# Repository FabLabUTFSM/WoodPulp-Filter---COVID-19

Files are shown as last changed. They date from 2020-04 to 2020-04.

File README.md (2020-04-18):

# Wood Pulp Filter for Covid - 19

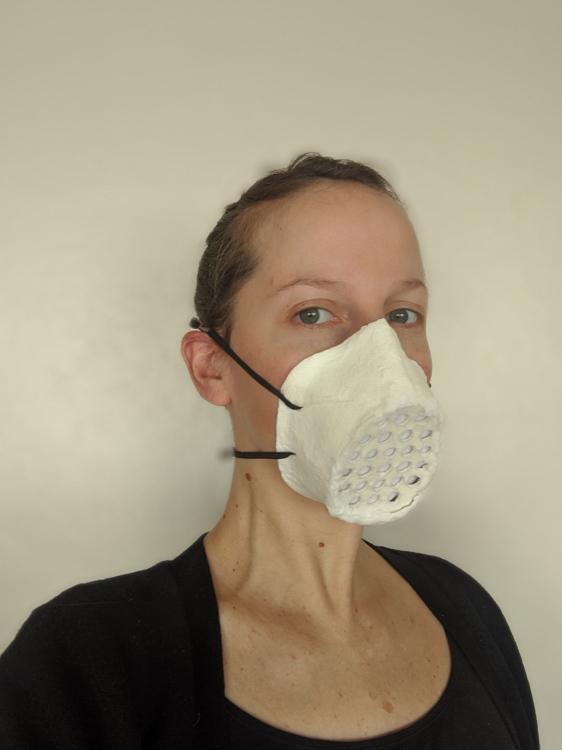
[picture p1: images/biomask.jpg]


This project is been developed by 
[Paloma Gonzalez](http://palomagr.mit.edu/index.html) and 
[José Tomás Domínguez](https://github.com/josetomas) in a collaboration of 
[Arauco ](https://www.arauco.cl)and [UTFSM Fablab](https://www.fablabs.io/labs/fablabutfsm).

COVID-19 has generated a global demand for face masks that our supply chains haven't been able to satisfy. Therefore, there is a huge need to create new materials and manufacturing methods to fabricate face masks and filters.  We are working on a wood pulp filter that protects from Covid - 19, and  could potentially be produced anywhere where there is a wood pulp factory. Wood pulp factories are present in most regions of the world.

Our goal is to physically modify wood pulp sheets to achieve the filtering performance of a N95 filter to produce a functional 
layer for respirators / masks / PPE for the corona viruses. 
[Wood pulp is the raw material for paper towels with the capacity of filtering particles of 0.3 μm.](https://smartairfilters.com/en/blog/paper-towel-effective-against-viruses-diy-mask/)
The corona virus measures approximately 0.1 μm. We can modify the compaction of the layers and/ or the size of the fibers to increase their filtering capacity / breathability. 

## Filter + Half Face Mask
**According to our calculations the half mask will cost $0,12 and the filter will cost $0,1.**  We will make updates to the cost whenever we have new info. We still aim for the cheapest possible option.

We are also developing a face mask which filters can be exchanged, 
completely out of molded wood pulp, taking advantage of our raw material.
[Our design is based on Wasp’s design](https://www.3dwasp.com/en/3d-printed-mask-from-3d-scanning/) but we are looking to work with molding 
and/or 2 mold processes instead of 3D printing. It is crucial to be able to mass produce the half masks. 

The advantage of Wasp design is that shape is ergonomic and the filters are held on the inside side of the mask, decreasing the contamination of the filters when changing them. 
There are also fabric masks in which these filters could work [like this one, the HKMask](https://diymask.site/). [We found carboard masks that also do the trick](http://bumask.ru/eng)

Molded wood pulp is meant to be a disposable material and it is 100% biodegradable as all the additives we are suing are. 
This is a characteristic that we want to take advantage of as after the pandemic we wouldn't want to have 
polluted the environment with more waste. This also means that the half masks will last less than N95 or other masks. We embrace such short temporality, and will 
asses it to notice our users. We expect that these protective equipment lasts 3 to 4 weeks.

## Filter Key Parameters to measure [[2](https://scientificfilters.com/wp-content/uploads/2016/03/BasicFiltrationConcepts.pdf)]
- Scanning Electron Microscope [SEM](https://en.wikipedia.org/wiki/Scanning_electron_microscope): This tests characterize the materials porosity. Target: < 0.1 um. 
        - **Update:** Camron did [SEM](SEM.md) imaging.
- Particle Retention Rate: "In a filtration process, the particle retention efficiency of a depth-type filter is expressed in terms of the particle size (in µm) at which a retention
level of 98% of the total number of particles initially challenging the filter is
obtained". Target: 95%
- Preassure Drop: The higher the pressure drop, the harder it is to breathe. Target: <5.82 [mmH20] at a flow rate of 32 [L/min]. 

We are following [FDA COVID-19 Face Mask Public Health Guidelines ](https://gitlab.cba.mit.edu/palomagr/wood-pulp-filter/-/blob/master/References/COVID19-Face-Masks-Guidance.pdf)

All this tests could be replaced by a DOP ([DOP Guideline](http://www.eacoontario.com/pdf/2013/Revised%20August%2027%202013%20DOP%20PAO%20HEPA%20IntegrityTesting%20Procedure.pdf)). 

## Filter Development
Wood pulp sheets have the following disadvantages:
- Hydrophilic, absorbs any liquid very fast so it could have a lower life expectancy and could absorb contaminated droplets, this can be controlled through design or modifying the material properties. 
- Due to air flow, the user could inhale wood pulp fibers, we are adding wood pulp based fabrics to act as a filter. It’s relevant to point out that wood fibers aren’t toxic, you just can’t digest them. 
- These filters will have a shorter life than plastic filters, we expect them to be replaced every 4 hours.  

### Raw Material for the filter and mask

Celulose comes in letter size sheets, 21.59 cm. X 27.94 cm with a thikness of 1mm.

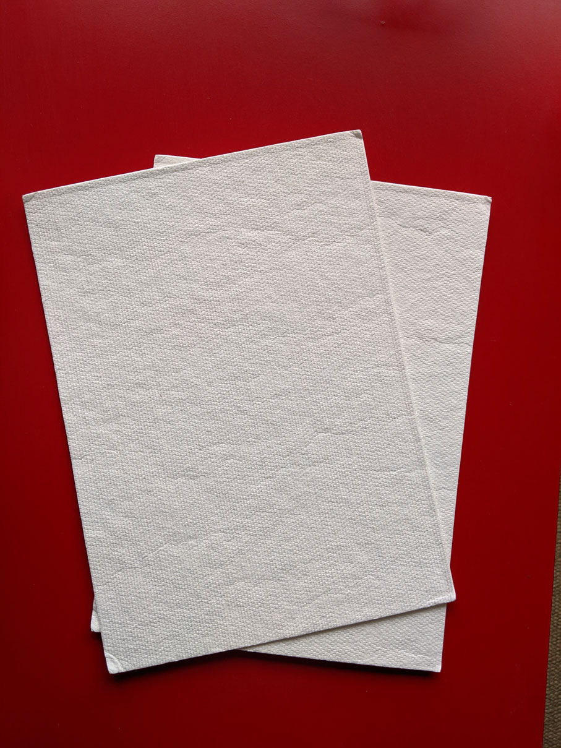
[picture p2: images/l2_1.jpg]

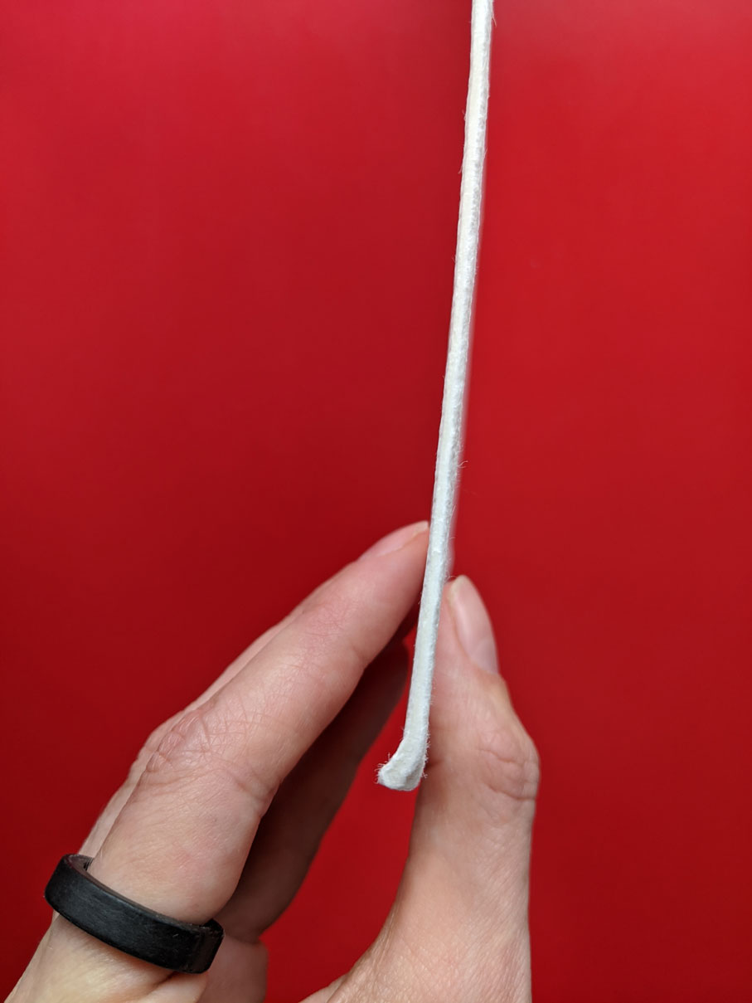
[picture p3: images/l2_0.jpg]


### Fabricating the filter

Due to the density of the cellulose sheets the material is not breathable. We succeeded in testing the feasibility of making it breathable. We pulverized it and compacted it into a breathable filter of 5mm thickness. The filter has three layers, the first and last of fabric to isolate fibers and possibly waterproof the pulp.
The filter needs to be tested to evaluate its filtering capacity and porosity.

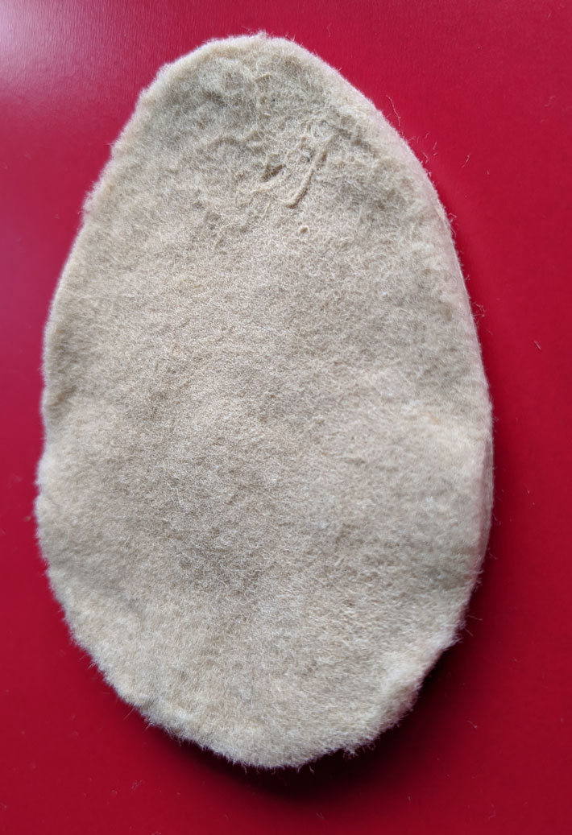
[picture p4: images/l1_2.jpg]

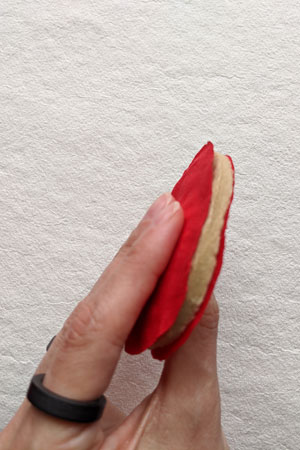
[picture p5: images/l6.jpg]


### Assembling the mask

We are working with the face mask design by [Wasp](https://www.3dwasp.com/en/3d-printed-mask-from-3d-scanning/)

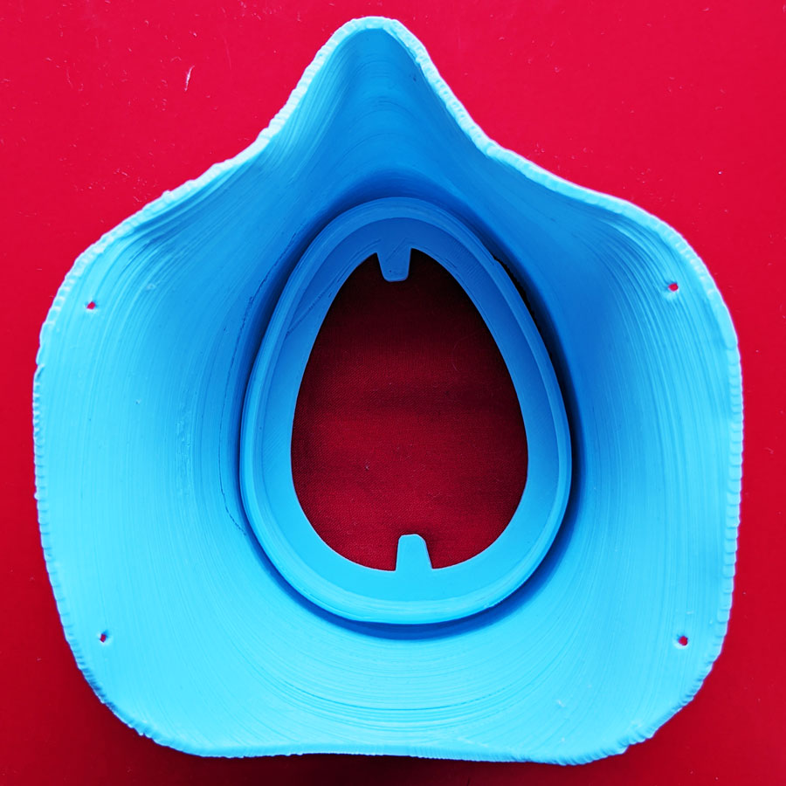
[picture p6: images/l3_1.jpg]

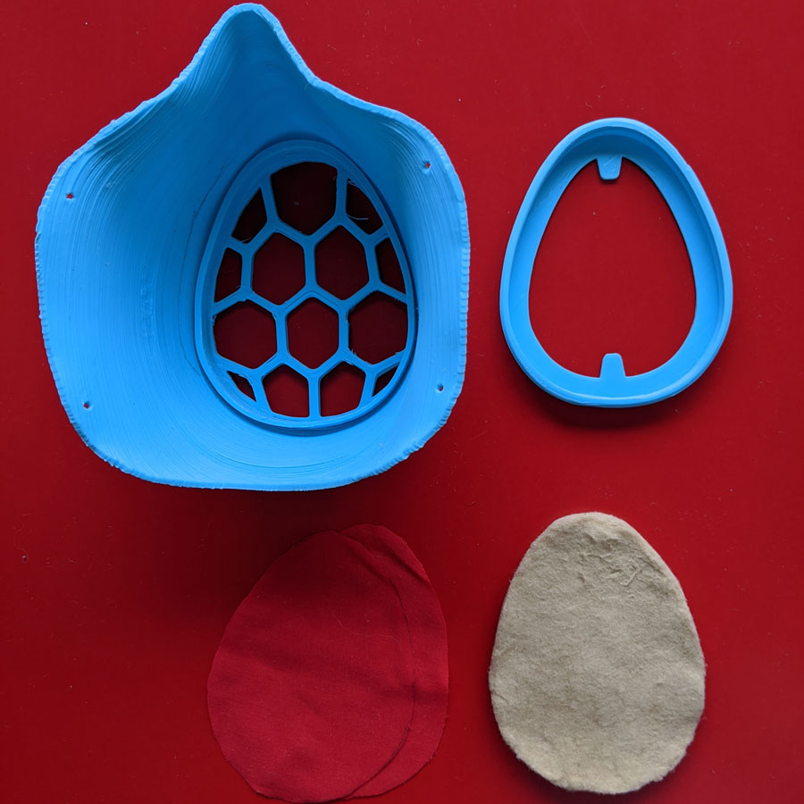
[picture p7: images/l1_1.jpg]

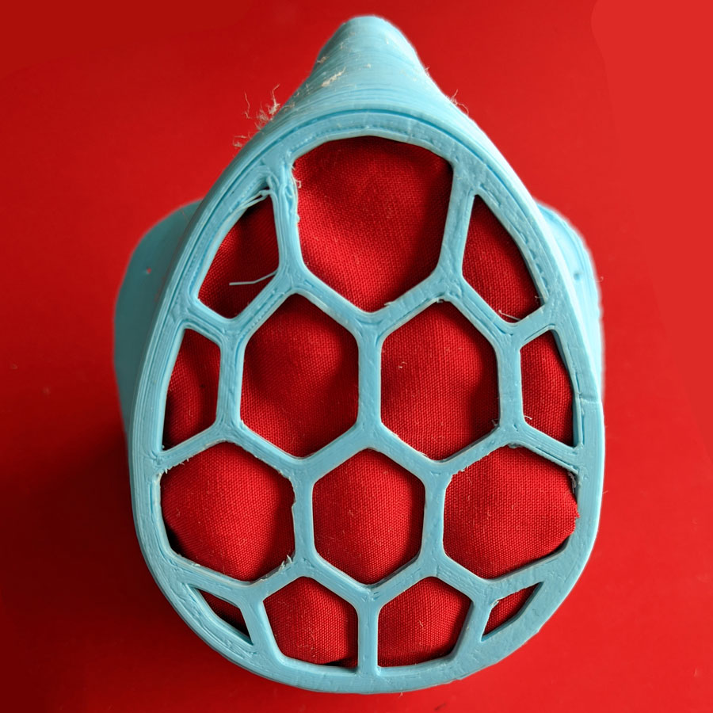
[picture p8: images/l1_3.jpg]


When everything is already manufactured, assemble the parts, and get a finished face mask with a replaceable wood pulp based filter. 

## Pulp Molding

In order to advance into mass production of the mask, we have been developing a 3D printed wood pulp mold, based on [Startasys](https://www.stratasysdirect.com/technologies/fused-deposition-modeling/fdm-tools-paper-pulp-molding). 

### Wood Pulp Molds

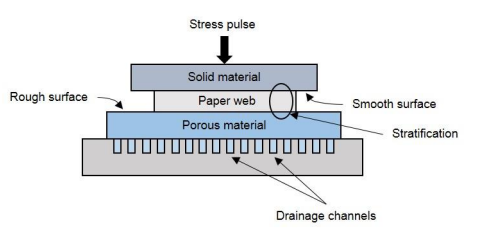
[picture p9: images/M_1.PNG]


In the image above [[3](https://onlinelibrary.wiley.com/doi/abs/10.1002/pts.2289)] you can see how Wood Pulp Molds work. 
The first part, called the moving half, of the mold is made from a solid material, and is the one that press the second part. 
The second part, called the fixed half, has two different layers, this allows the water to flow through the fiber network, into a porous material, to the drainage channels (as you can see in the image above); this allows the mold to release water and keep its final form. 

### First iteration

#### The Mold for Pulp Molding
You can find the mold .stl files in the following [link](https://github.com/FabLabUTFSM/WoodPulp-Filter---COVID-19/tree/master/3D_Models). 

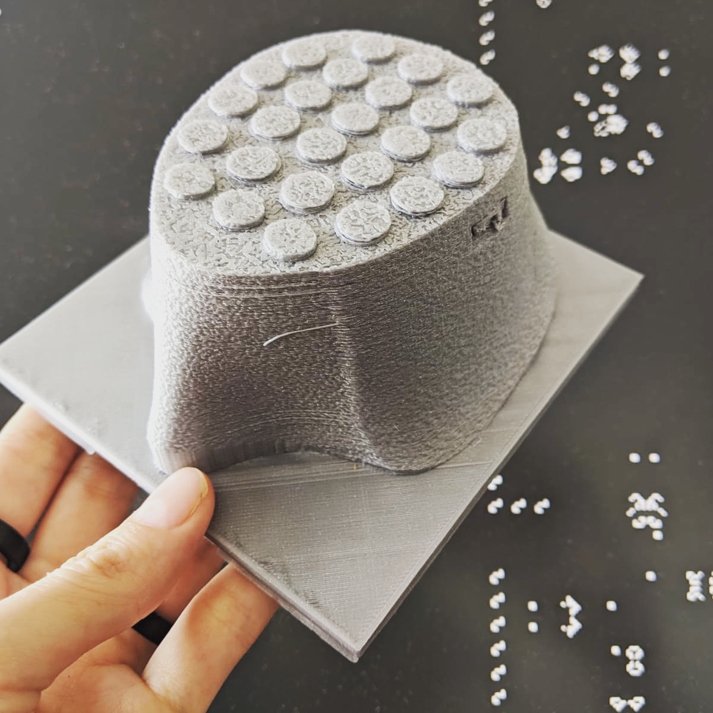
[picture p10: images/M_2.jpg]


(Models M_1 correspond to the iteration)

#### Material Formula

We used the following foormula for the first test:

- Pulverized unbleached wood pulp: 11.3 grams

It has to have the following texture:

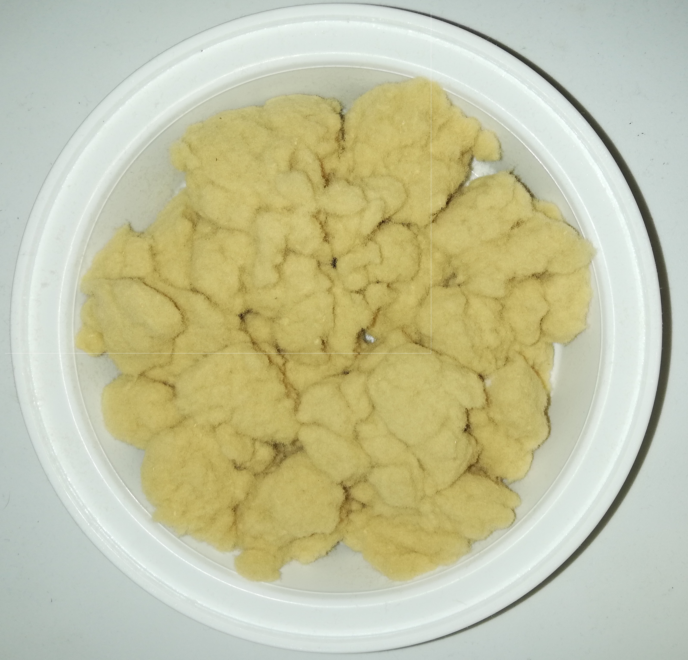
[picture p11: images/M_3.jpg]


- Water: 269 grams
- Polyvinyl acetate: 66.3 grams. 

#### Results

In the following pictures you can see the first results we got:

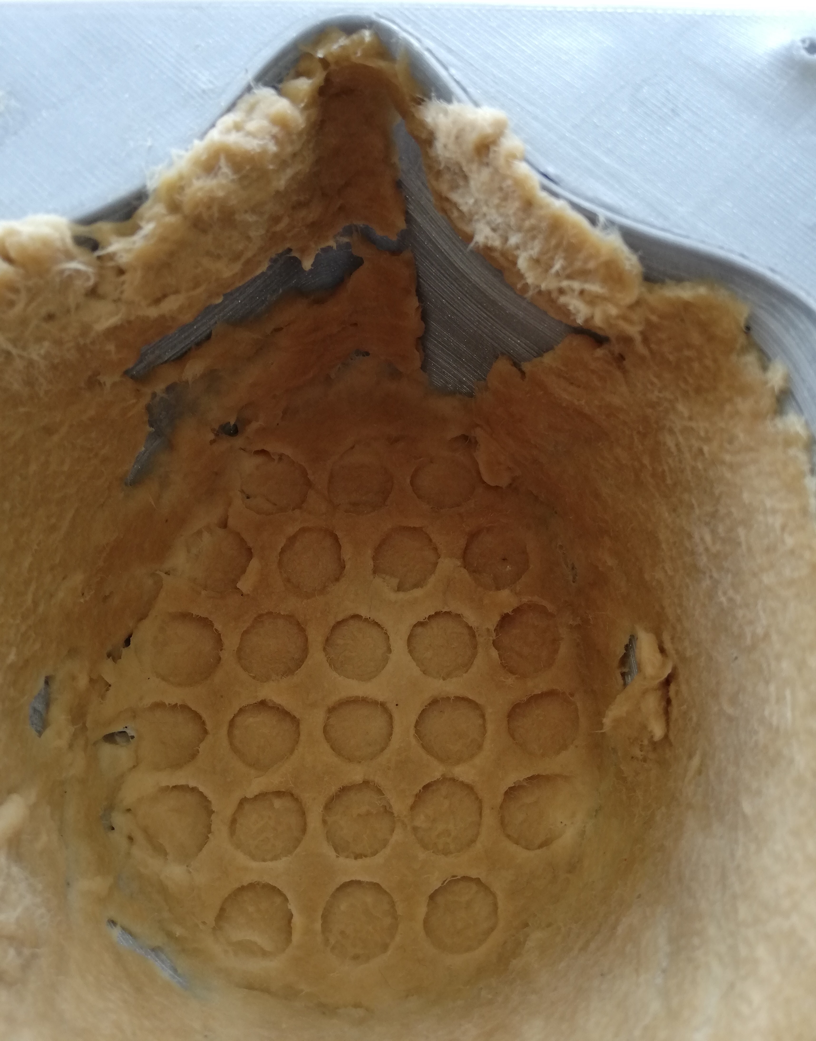
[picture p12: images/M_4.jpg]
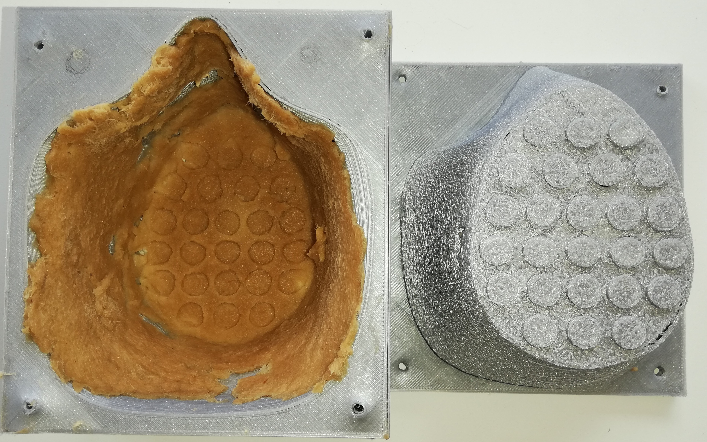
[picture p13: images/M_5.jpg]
 

#### Conclusions

- After 12 hours of drying, the material was wet. We will improve the geometry and introduce porosity that expells the water out. 
- The porous material layer of the fixed half must have a 1 mm thickness. 
- We must add drain channels to the fixed half. 
- The material is getting a good resolution. 
- The cylinders for the respiration holes must be extended.

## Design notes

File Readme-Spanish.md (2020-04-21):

# Filtro de Celulosa para Covid - 19



Este proyecto esta siendo desarrollado por:
[Paloma Gonzalez](http://palomagr.mit.edu/index.html) and 
[José Tomás Domínguez](https://github.com/josetomas), en colaboracion con 
[Arauco ](https://www.arauco.cl)y [UTFSM Fablab](https://www.fablabs.io/labs/fablabutfsm).

COVID-19 ha generado una demanda global de máscaras faciales que nuestras cadenas de suministro no han podido satisfacer. Por lo tanto, 
existe una gran necesidad de crear nuevos materiales y métodos de fabricación para máscaras faciales y filtros en Chile y Latinoamérica. 
Estamos trabajando en un filtro de celulosa de madera que protege de Covid - 19, y podría producirse en cualquier lugar donde 
haya una fábrica de celulosa. Las fábricas de celulosa están presentes en la mayoría de las regiones del mundo. 

Nuestro objetivo es modificar físicamente las láminas de pulpa de madera para lograr el rendimiento de filtrado de un filtro N95 para producir
un filtro para respiradores / máscaras / PPE para los virus corona. 

[La celulosa es el material con que se fabrica el papel tissue que tiene una capacidad de filtración de partículas de 0.3 μm.](https://smartairfilters.com/en/blog/paper-towel-effective-against-viruses-diy-mask/)
Los virus corona son de aproximadamente 0.1 μm. Podemos modificar la compactación de las capas y 
/ o el tamaño de las fibras para aumentar su capacidad de filtración / respirabilidad.

------
También estamos desarrollando una máscara facial que puede intercambiar filtros,
completamente de celulosa madera para poder utilizar nuestra materia prima.
[Nuestro diseño está basado en el de Wasp.](https://www.3dwasp.com/en/3d-printed-mask-from-3d-scanning/) pero lo vamos a desarrollar en cartón moldeado
en vez de impresión 3D ya el costo es significativamente más bajo, y el proceso más rápido. Es fundamental el poder producir las máscaras industrialmente.

La ventaja del diseño Wasp es que el filtro se introduce en el interior de la máscara, lo que lo protege de agentes externos. Creemos que este
detalle va a contribuir a reducir la contaminación de los filtros. también existen máscaras de tela para las cuales podría servir el filtro
que estamos desarrollando, [como por ejemplo esta, la HKMask](https://diymask.site/).

## Parámetros Clave a Medir [[2](https://scientificfilters.com/wp-content/uploads/2016/03/BasicFiltrationConcepts.pdf)]
- Microscopio electrónico de barrido [SEM](https://en.wikipedia.org/wiki/Scanning_electron_microscope): Estas pruebas caracterizan la porosidad de los materiales. Objetivo: <0.1 um.
- Tasa de retención de partículas: "En un proceso de filtración, la eficiencia de retención de partículas de un filtro de tipo de profundidad se expresa en términos del tamaño de partícula (en µm) en el que se mantiene
El nivel del 98% del número total de partículas que desafían inicialmente el filtro es
obtenido ". Objetivo: 95%
- Caída de presión: cuanto mayor es la caída de presión, más difícil es respirar. Objetivo: <5.82 [mmH20] a una velocidad de flujo de 32 [L / min]. 

Todas estas pruebas podrían reemplazarse por un [DOP](http://www.eacoontario.com/pdf/2013/Revised%20August%2027%202013%20DOP%20PAO%20HEPA%20IntegrityTesting%20Procedure.pdf).

## Pasos Clave: 
- Mediciones SEM, miden la porosidad de las láminas de pulpa de madera; debe ser> 0.1um
- Medición de conteo de partículas, medir la capacidad de filtrado del material, el escenario ideal será una capacidad de filtrado N95.
- En caso de que la porosidad del material sea mayor a 0.1um o la capacidad de filtrado no sea suficiente, Arauco modificará su proceso de fabricación para obtener un material más ajustado, o vamos a probar una máquina de electrohilado.
- Hacer el material hidrofóbico.
-Producción industrial.

## Desarrollo de filtros
- Las láminas de celulosa de madera tienen las siguientes desventajas: Hidrofílico, absorbe cualquier líquido muy rápido,
por lo que podría tener una esperanza de vida más baja y podría absorber las gotas contaminadas, esto se puede controlar
mediante el diseño o la modificación de las propiedades del material. 
- Debido al flujo de aire, el usuario podría inhalar fibras de pulpa de madera, estamos agregando telas a base de pulpa de madera
para que actúen como filtro. 
- Es importante señalar que las fibras de madera no son tóxicas, simplemente no se pueden digerir. 

## Estado Actual

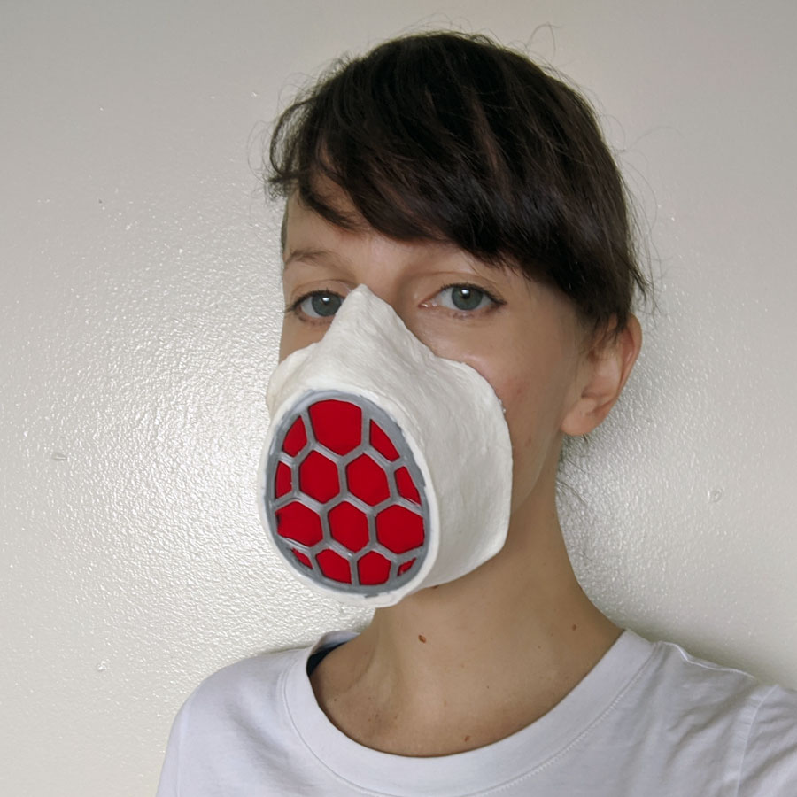
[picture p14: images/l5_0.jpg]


Estamos trabajando en una versión hecha de pulpa de madera en lugar de impresión 3D para producir en masa con moldeado de
cartón, similares a las bandejas de huevos. El marco del filtro todavía se imprime en 3D. Nuestro siguiente paso es
incorporarlo en el molde y hacerlo con pulpa de madera. **De acuerdo a nuestros calculos la media mascara va a costar 25-50$ pesos chilenos, 
y el filtro va a costar 80-90$ pesos chilenos.**

### Materias Primas

Las laminas de celulosa tienen 1x1.5m y 1mm de espesor.




También estamos trabajando con telas a base de pulpa de madera,
que actuarán como filtro de fibras de pulpa de madera de gran tamaño que podrían desprenderse del filtro debido al flujo de aire:

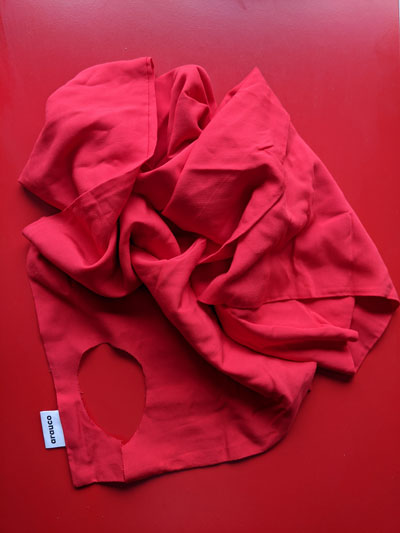
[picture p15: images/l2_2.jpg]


### Fabricación de filtros

Debido a la densidad de las láminas de celulosa, el material no es respirable.
Logramos probar la viabilidad de hacerlo transpirable. Lo pulverizamos
y lo compactamos en un filtro transpirable de 5 mm de espesor.
El filtro tiene tres capas, la primera y la última de tela para aislar las fibras y posiblemente impermeabilizar la celulosa.
El filtro necesita ser probado para evaluar su capacidad de filtrado y porosidad.




### Montar la Máscara

Estamos trabajando con el diseño de la máscara facial por [Wasp](https://www.3dwasp.com/en/3d-printed-mask-from-3d-scanning/)



Cuando todo ya está fabricado



Montamos las piezas:

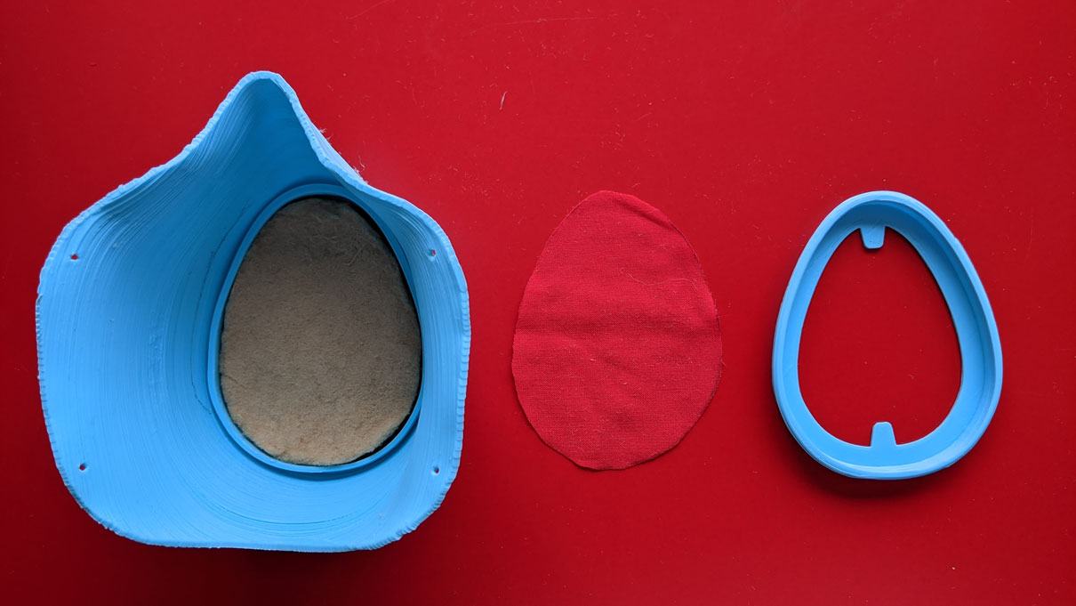
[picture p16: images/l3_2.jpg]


Y obtenemos una máscara facial terminada, con un filtro intercambiable a base de pulpa de madera.



## Moldeado de la Celulosa
Para avanzar en la producción en masa de la máscara, hemos desarrollado un
molde de pulpa de madera impreso en 3D, basado en los moldes de [Startasys](https://www.stratasysdirect.com/technologies/fused-deposition-modeling/fdm-tools-paper-pulp-molding). 

**El objetivo es generar un proceso de diseño similar a la producción de moldes para cartón moldeado, pero con las técnicas de fabricación digital. 
Nuestra meta es poder agilizar la fabricación del molde y así comenzar la producción masiva de nuestra mascara.**

### Esquema de Moldes para Celulosa



En la imagen [[3](https://onlinelibrary.wiley.com/doi/abs/10.1002/pts.2289)] se puede observar como funcionan los moldes para pulpa de madera / papel. 
La primera parte, llamada la mitad móvil, del molde está hecha de un material sólido, y es la que presiona la segunda parte.
La segunda parte, llamada la mitad fija, tiene dos capas diferentes, esto permite que el agua fluya a través de la red de fibra, hacia un material poroso,
hacia los canales de drenaje (como puede ver en la imagen de arriba). Esto permite que el molde libere agua y mantenga su forma final.
### Primera Iteración

#### Molde
Los archivos del molde se pueden encontrar aqui [link](https://github.com/FabLabUTFSM/WoodPulp-Filter---COVID-19/tree/master/3D_Models). 


(Models M_1 correspond to the iteration)

#### Formula para el Material

Usamos la siguiente formula para la primera prueba de material:

- Celulosa pulverizada sin blanquear 11.3 gramos. 

Tiene que tener la siguiente textura:



- Agua: 269 gramos
- Acetato de polivinilo: 66.3 gramos. 

#### Resultados

En las siguientes imágenes se puede ver el primer resultado.
Vale la pena destacar que el material permite una resolución aceptable de la geometría del molde.

 

#### Conclusions

- Después de 12 horas de secado, el material estaba húmedo. Mejoraremos la geometría e introduciremos la porosidad que expulsa el agua.
- La capa de material poroso de la mitad fija debe tener un espesor de 1 mm.
- Debemos agregar canales de drenaje a la mitad fija.
- El material está obteniendo una buena resolución.
- Los cilindros para los orificios de respiración deben extenderse.

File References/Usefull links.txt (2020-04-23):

https://www.fda.gov/medical-devices/personal-protective-equipment-infection-control/n95-respirators-and-surgical-masks-face-masks  | Respirator analisys

https://fastlifehacks.com/n95-vs-ffp/ | Todo sobre mascaras

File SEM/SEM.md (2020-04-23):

# Arauco Wood Pulp Manufacturer

Base Analysis developed by [Camron Blackburn.](https://gitlab.cba.mit.edu/camblackburn)

## BKP - Radiata Pine Wood Pulp
Manufacturer page: [Arauco BKP](https://www.arauco.cl/na/marcas/woodpulp/arauco-bkp/)

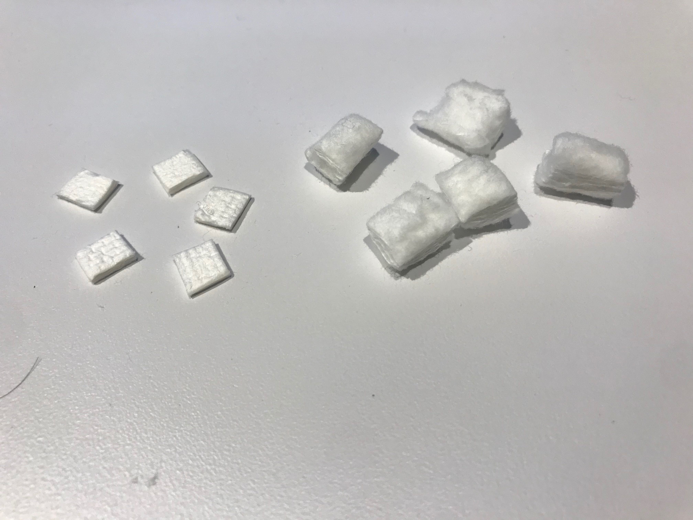
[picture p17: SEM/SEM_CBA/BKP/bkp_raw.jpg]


### physical measurements 
the pieces gold coated were imaged.

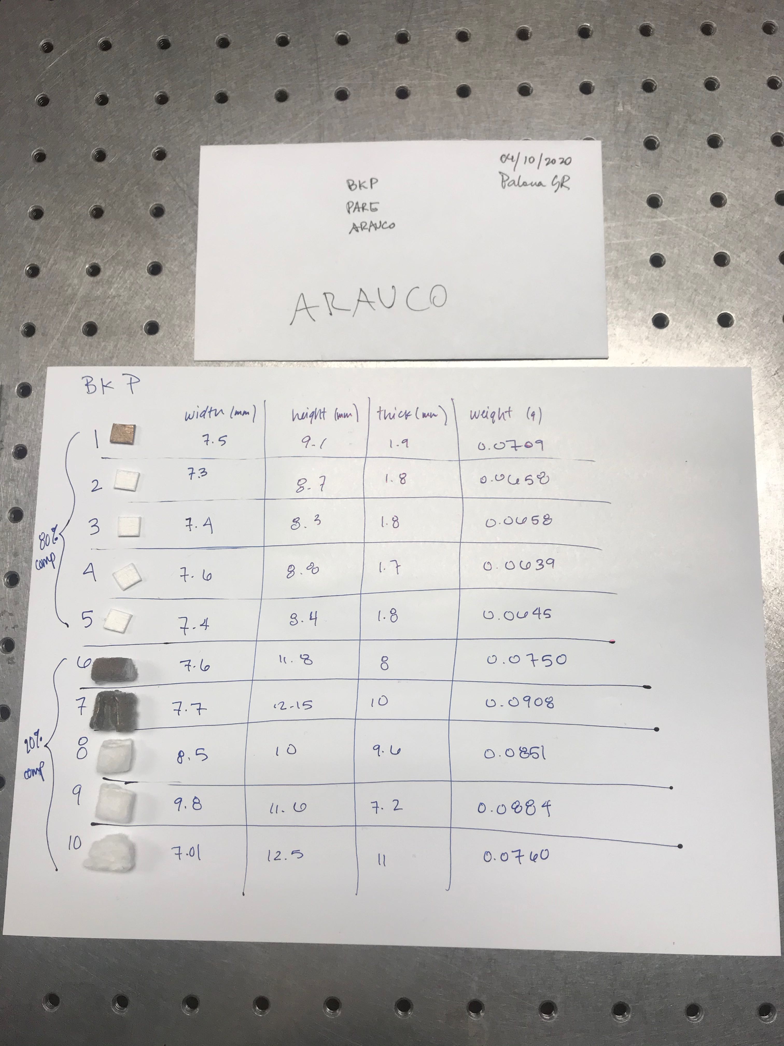
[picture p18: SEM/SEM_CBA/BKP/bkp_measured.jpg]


### imaging
#### 80% compacted
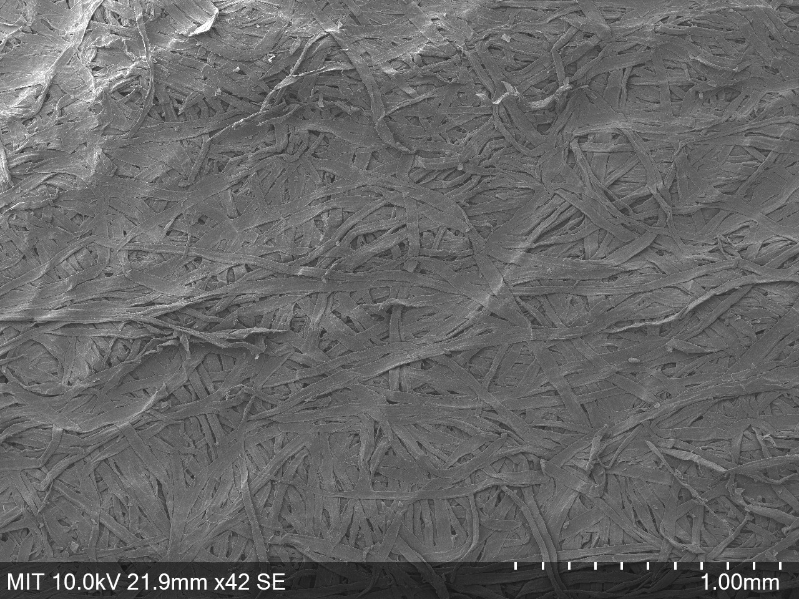
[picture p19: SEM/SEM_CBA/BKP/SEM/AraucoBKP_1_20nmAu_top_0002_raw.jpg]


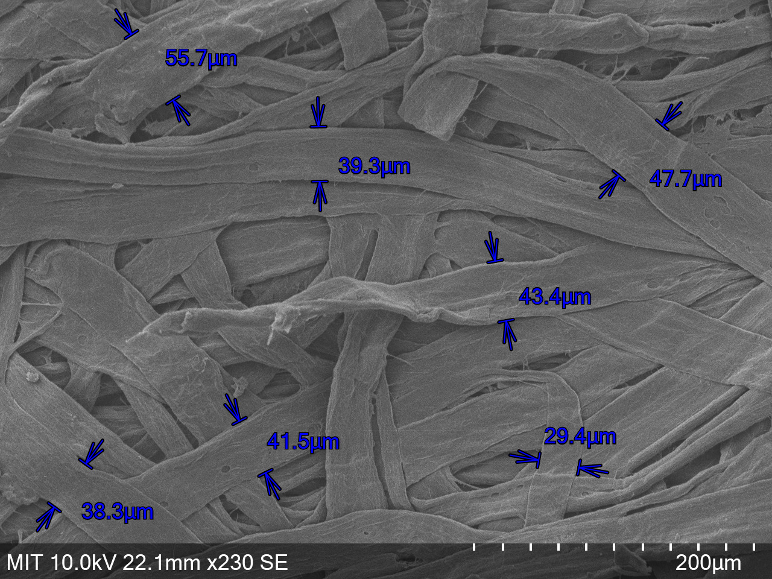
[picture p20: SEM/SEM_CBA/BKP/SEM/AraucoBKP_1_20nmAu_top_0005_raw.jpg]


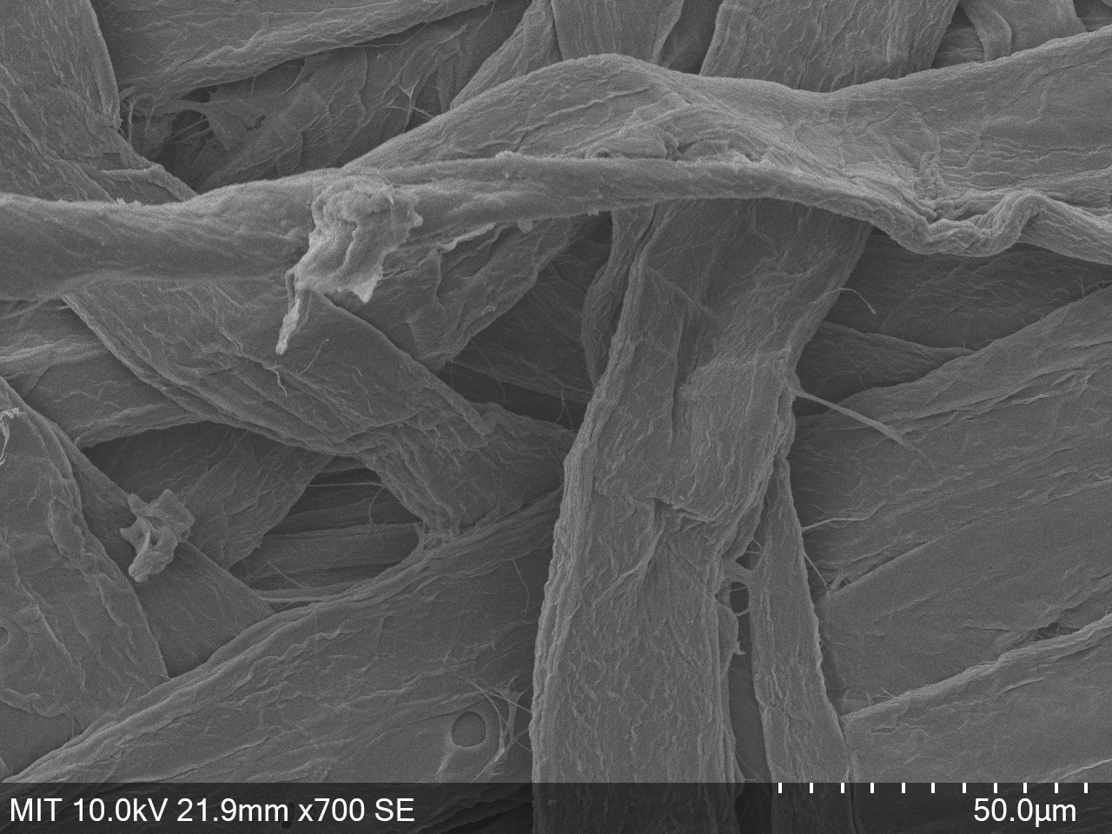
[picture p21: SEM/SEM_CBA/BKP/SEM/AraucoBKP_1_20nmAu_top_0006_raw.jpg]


#### 20% compacted
top view from #6

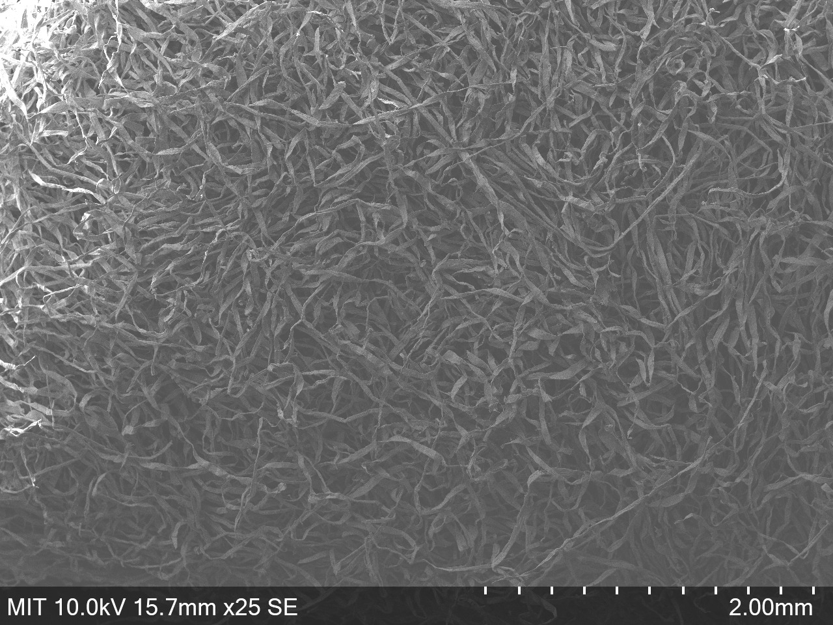
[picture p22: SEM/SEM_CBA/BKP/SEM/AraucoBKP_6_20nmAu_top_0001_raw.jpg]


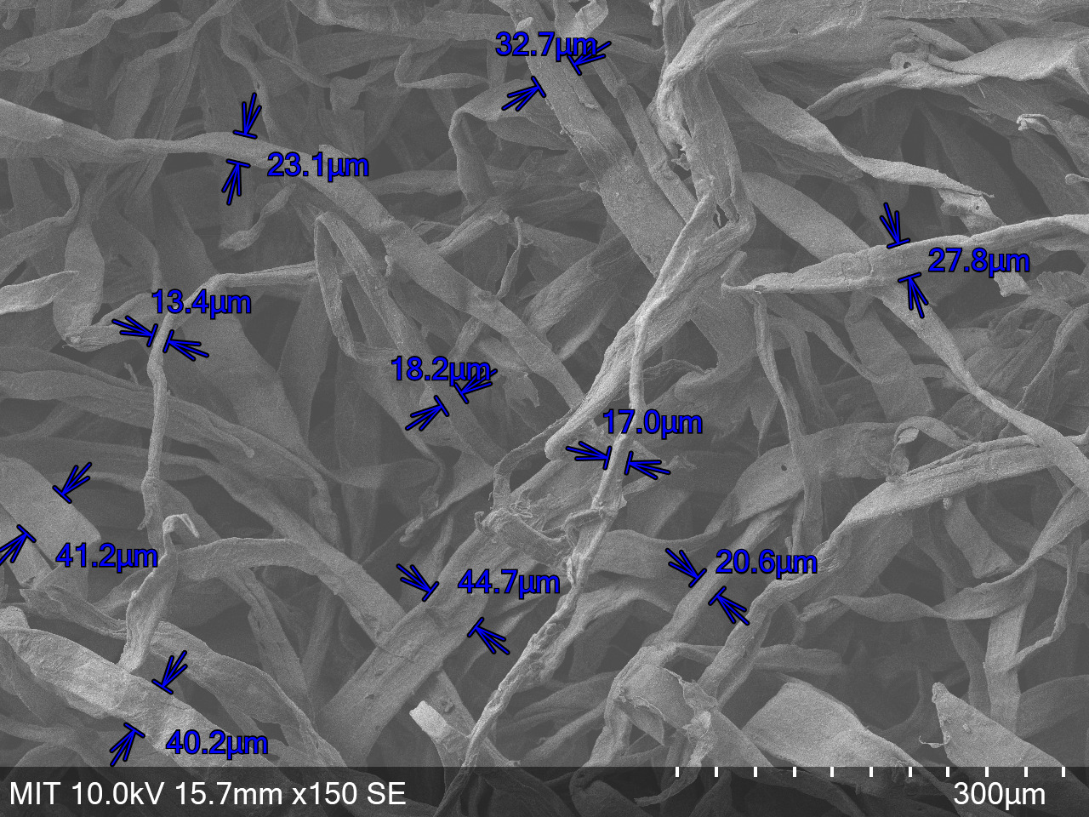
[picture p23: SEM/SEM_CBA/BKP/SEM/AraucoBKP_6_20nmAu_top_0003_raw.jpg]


side view from # 7
- you can see the layers that were more or less compacted

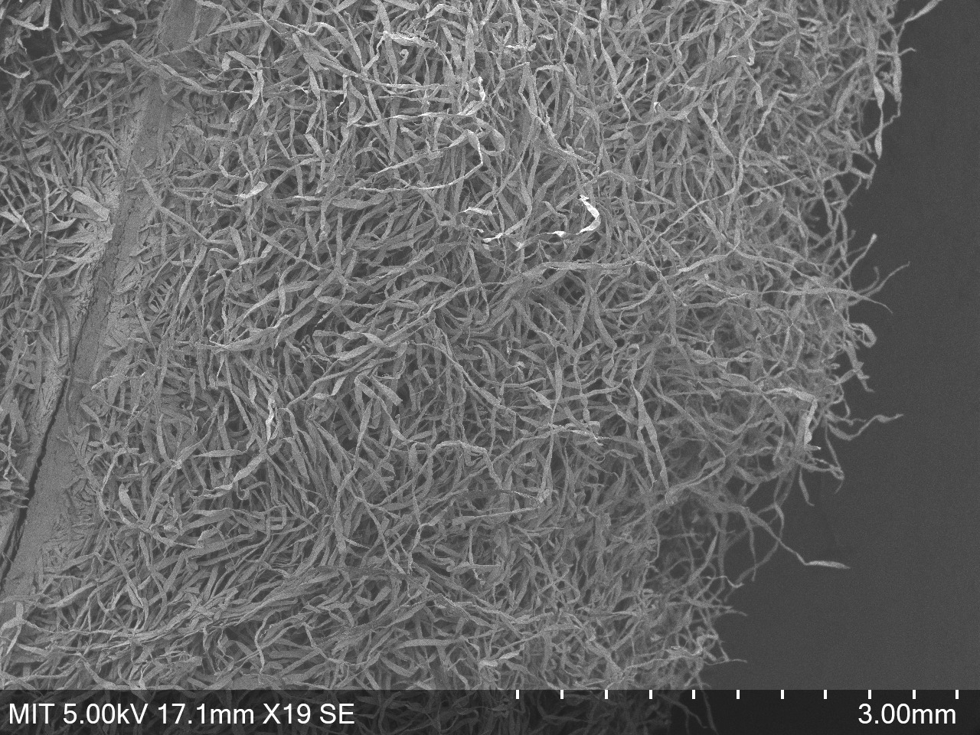
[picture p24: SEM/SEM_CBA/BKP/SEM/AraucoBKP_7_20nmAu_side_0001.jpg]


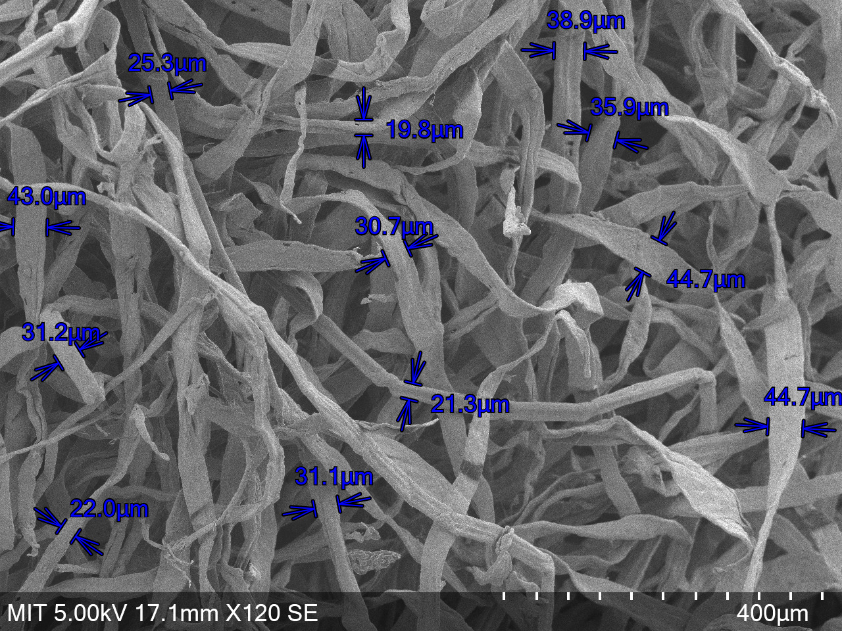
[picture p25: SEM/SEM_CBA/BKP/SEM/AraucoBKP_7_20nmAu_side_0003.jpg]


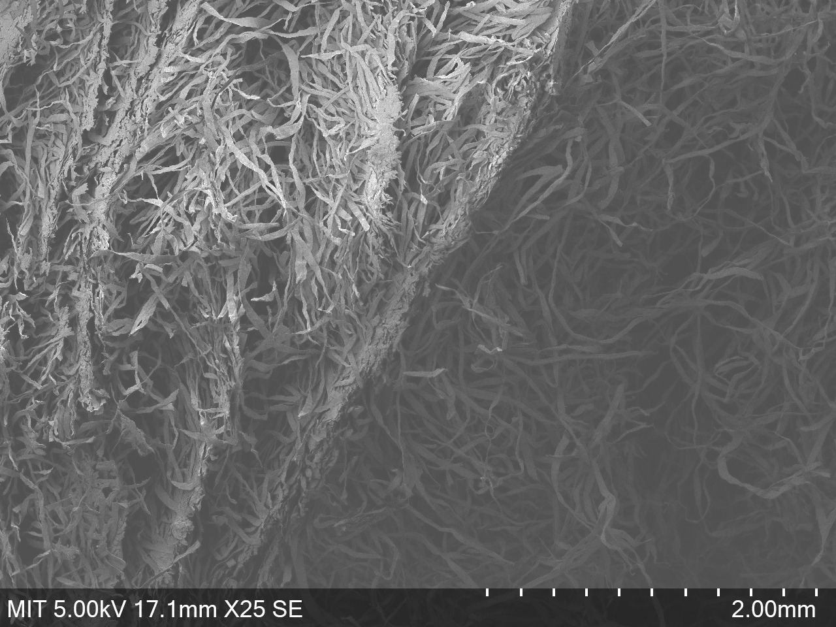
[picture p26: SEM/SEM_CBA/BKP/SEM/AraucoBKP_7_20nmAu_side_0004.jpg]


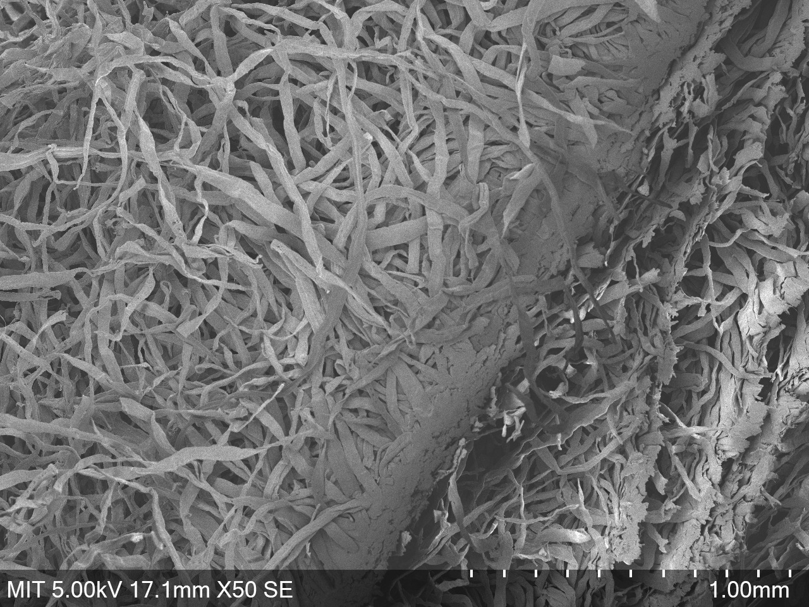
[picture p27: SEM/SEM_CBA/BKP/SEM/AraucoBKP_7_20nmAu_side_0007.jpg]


## EKP - Eucalyptus Wood Pulp
manufacturer page: [Arauco EKP](https://www.arauco.cl/aus-nz/marcas/woodpulp/arauco-ekp/)

### physical measurements
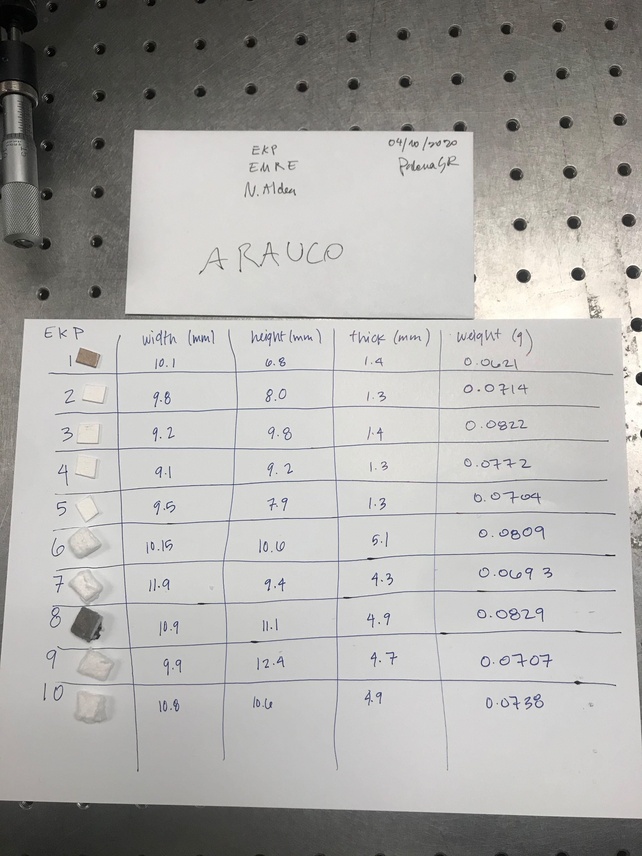
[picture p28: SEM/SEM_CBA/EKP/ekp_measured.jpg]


### imaging
#### 80% compacted
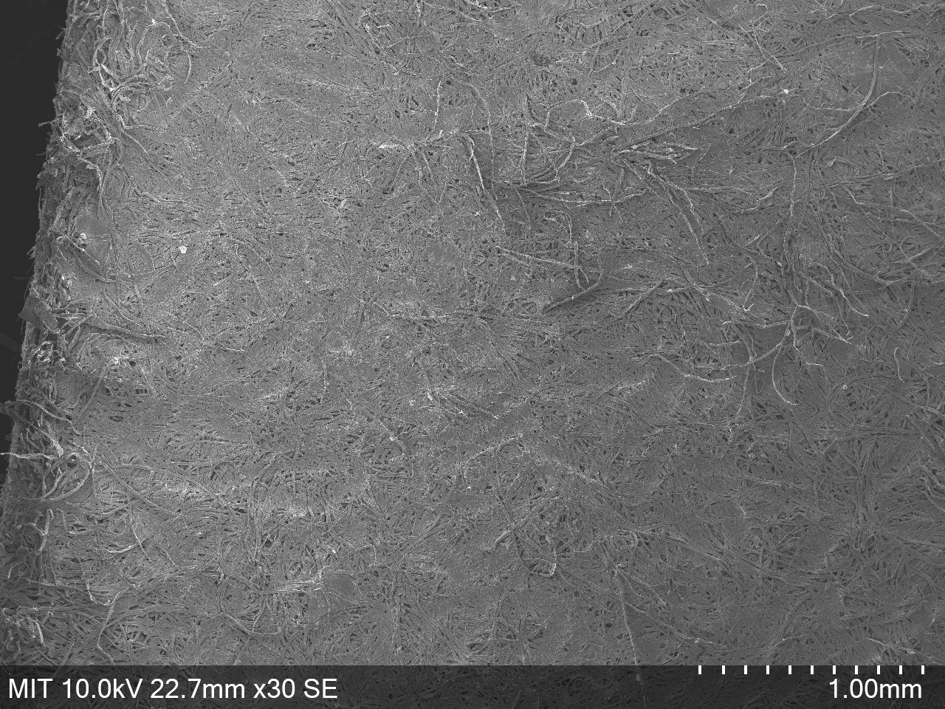
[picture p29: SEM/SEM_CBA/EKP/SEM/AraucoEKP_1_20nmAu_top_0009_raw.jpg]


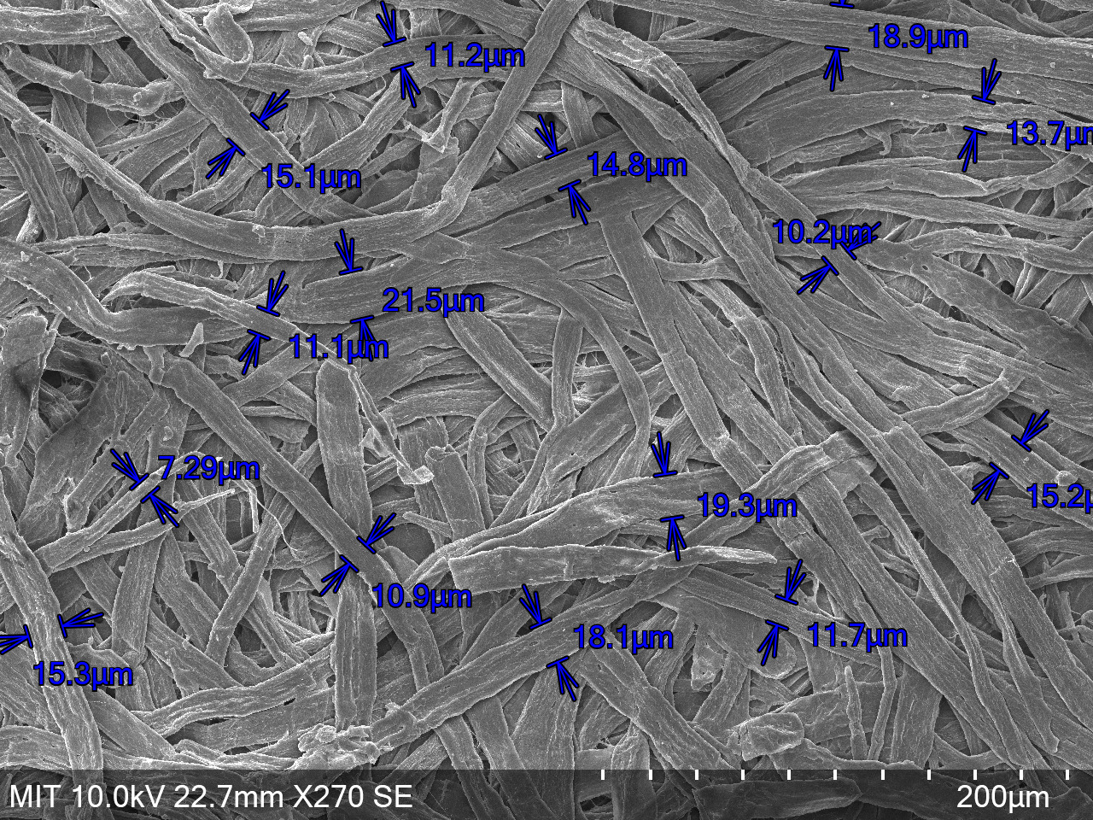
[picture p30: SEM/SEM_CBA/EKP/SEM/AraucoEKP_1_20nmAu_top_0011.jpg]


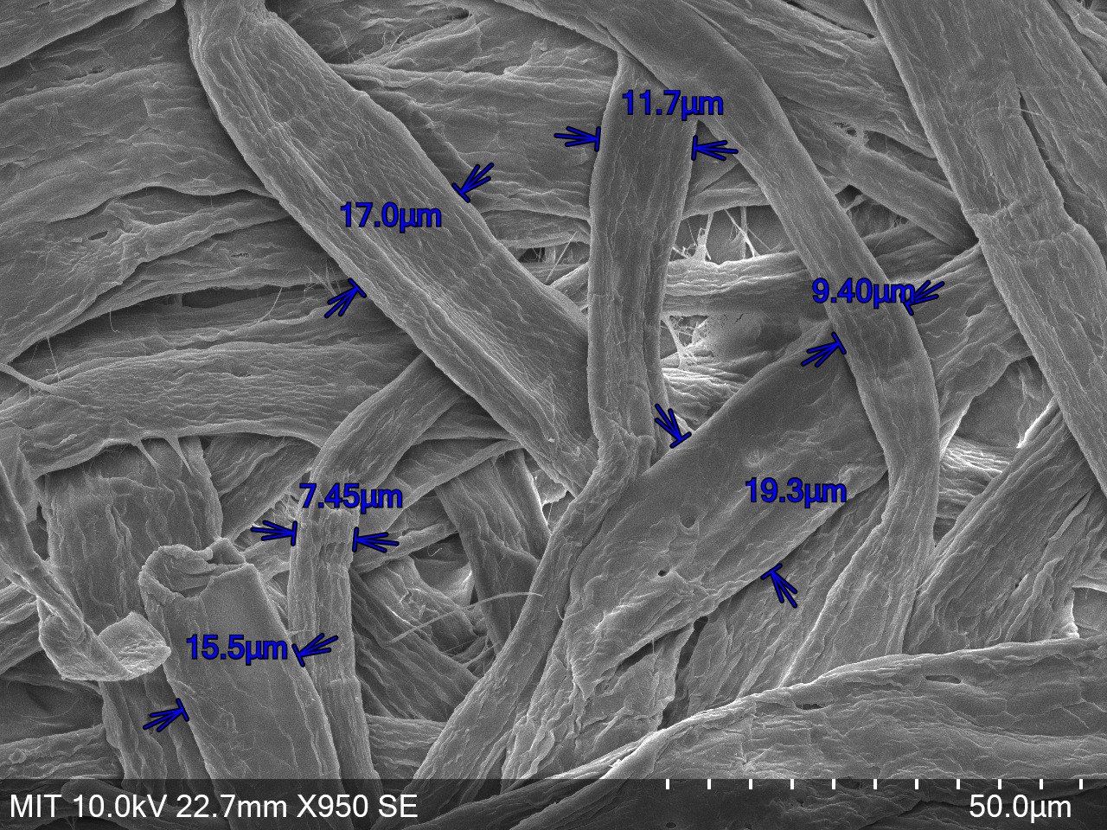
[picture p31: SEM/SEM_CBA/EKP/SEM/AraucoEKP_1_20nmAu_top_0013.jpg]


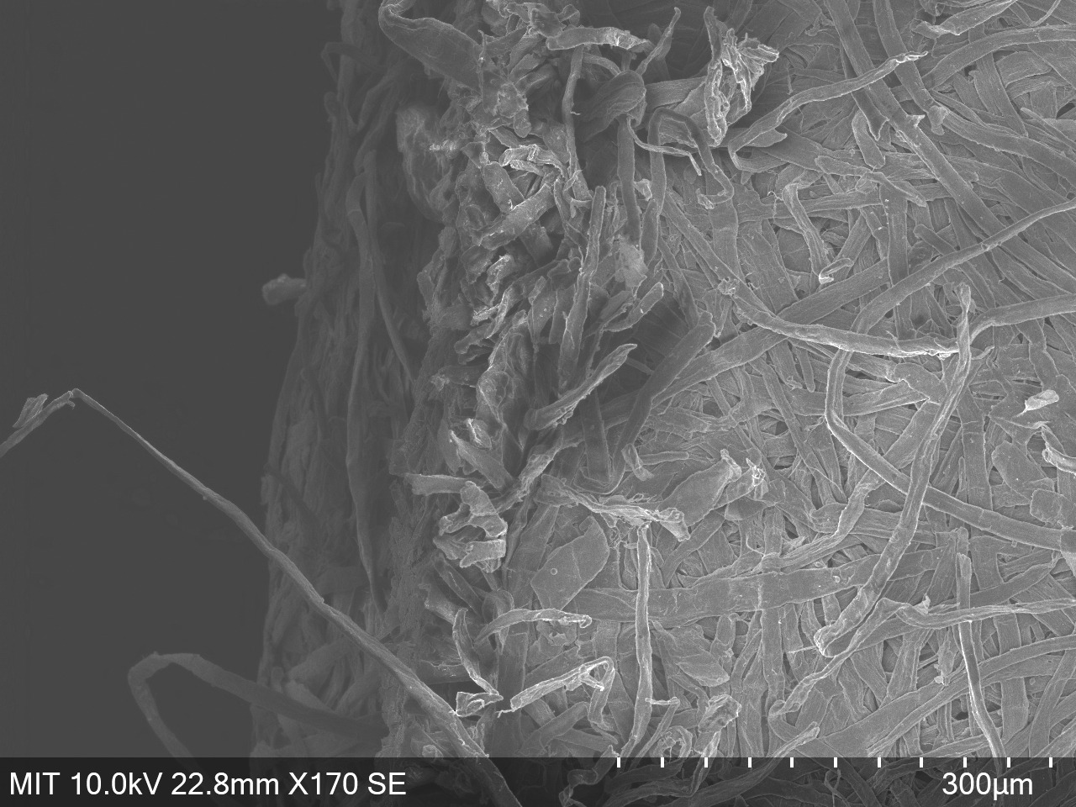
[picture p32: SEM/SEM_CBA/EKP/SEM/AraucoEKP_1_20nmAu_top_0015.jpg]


#### 20% compacted
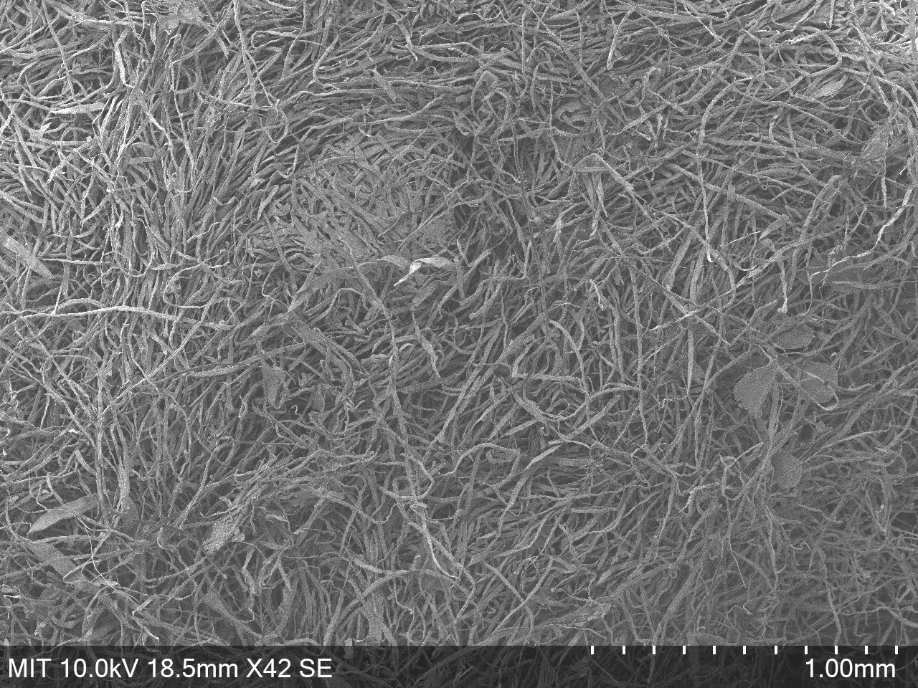
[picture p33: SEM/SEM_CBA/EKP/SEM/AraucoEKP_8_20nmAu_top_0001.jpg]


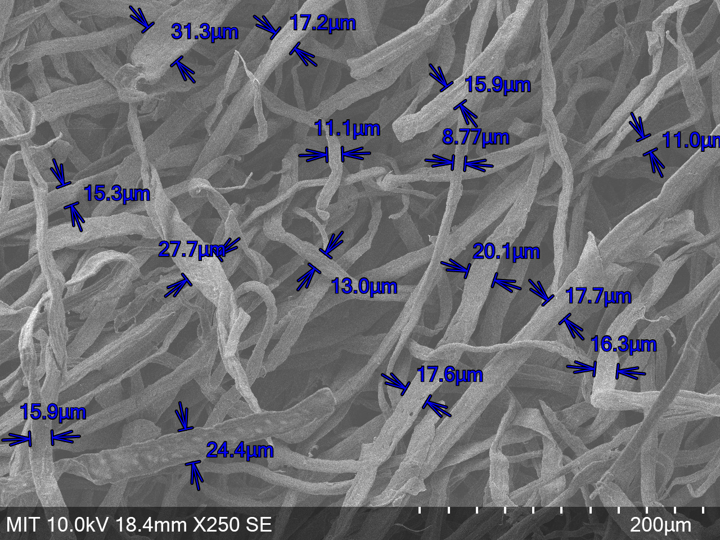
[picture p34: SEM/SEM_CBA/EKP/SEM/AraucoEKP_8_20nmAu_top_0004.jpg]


there are small, leaf-like features with tiny holes . . 

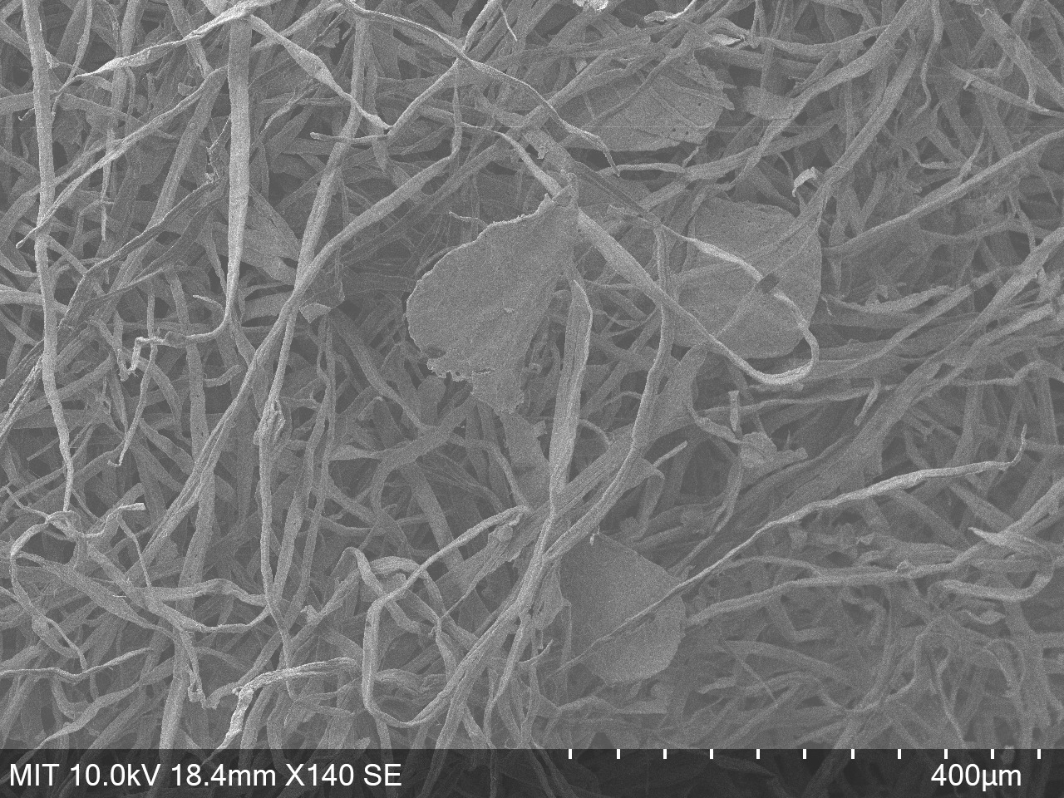
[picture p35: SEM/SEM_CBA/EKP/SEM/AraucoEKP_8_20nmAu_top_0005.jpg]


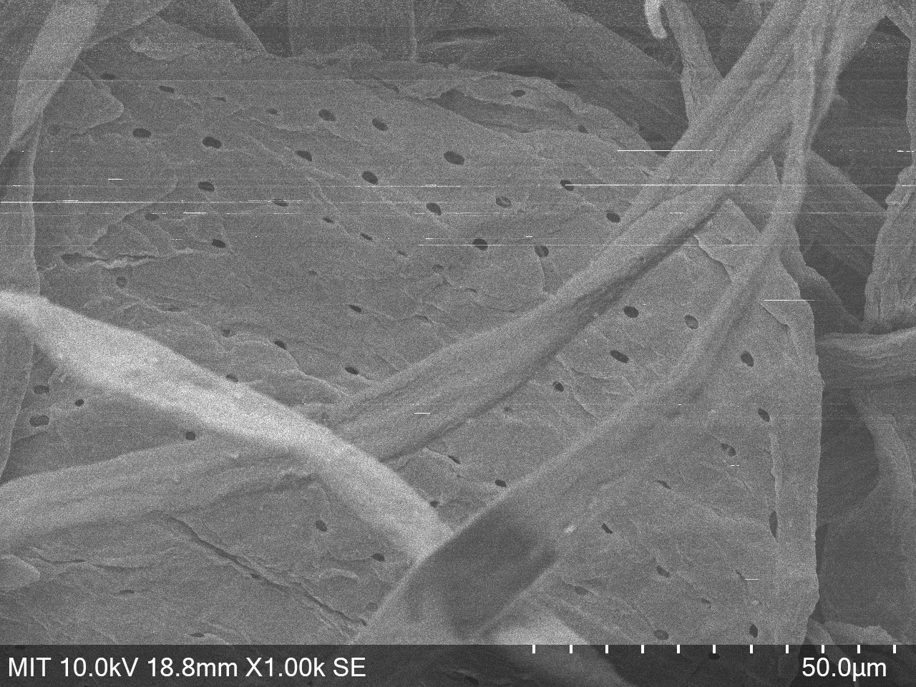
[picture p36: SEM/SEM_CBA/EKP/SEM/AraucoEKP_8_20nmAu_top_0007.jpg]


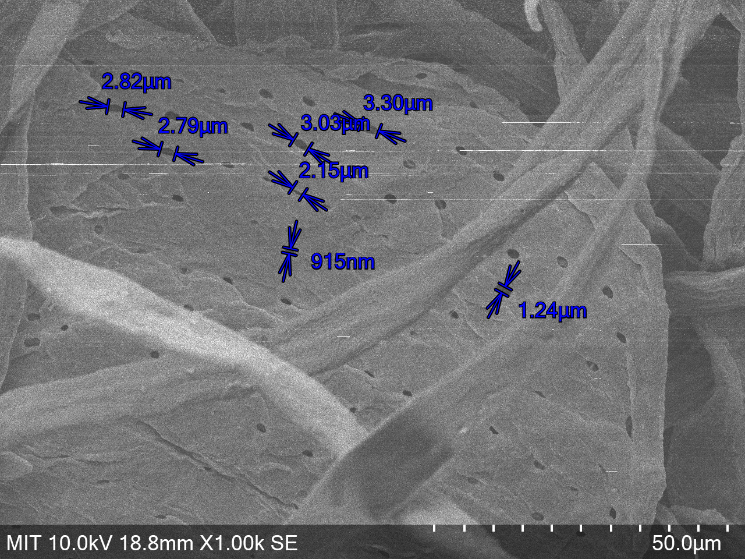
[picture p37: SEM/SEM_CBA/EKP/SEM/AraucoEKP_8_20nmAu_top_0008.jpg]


## UKP - Unbleached Radiata Pine Pulp
manufacturer page: [Arauco UKP](https://www.arauco.cl/na/marcas/woodpulp/arauco-ukp/)

### physical measurements


### imaging
#### 80% compacted










#### 20% compacted











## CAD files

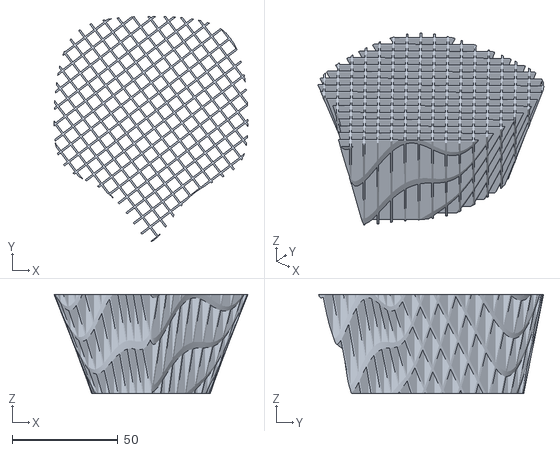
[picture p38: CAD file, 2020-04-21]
CAD/Prueba_Prusa_Interior_4mm.stl
91.9 x 106.6 x 47.0

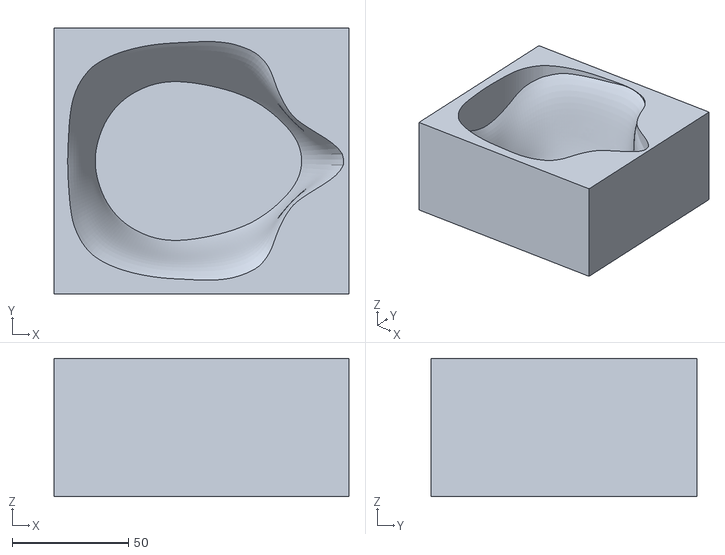
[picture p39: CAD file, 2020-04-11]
CAD/M_1_1.stl
127.0 x 114.7 x 59.5

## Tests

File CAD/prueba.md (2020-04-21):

#Perfiles Netfabb: 

## Lattice Grid
Recomendación de Stratasys. 

### Prusa

Unit size (x,y,z): 1.5
Lattice: 0.5 mm

### Formlabs
#### Lattice
Unit size (x,y,z): 1.5 mm
Lattice: 0.2 mm
Espesor de capa: 4mm
#### Surface Lattice
Max. Beam Length: 2 mm 
Lattice: 0.2 mm

## Lattice Vin Tiles

09/04
Formlabs: 
Lattice thikness: 0.2mm

Work? Perfect! 

16/04
Formlabs: 
Espesor Capa: 2.25 mm 
Lattice thikness: 0.2 mm
Latice size (x,y,z): 2,2,2 mm

17/04
Prusa: 
Espesor Capa: 2mm 
Lattice thikness: 1.2 mm
Latice size (x,y,z): 3,3,3 mm

relleno interior: 
Espesor: 0.8mm
Distantcia: 1mm

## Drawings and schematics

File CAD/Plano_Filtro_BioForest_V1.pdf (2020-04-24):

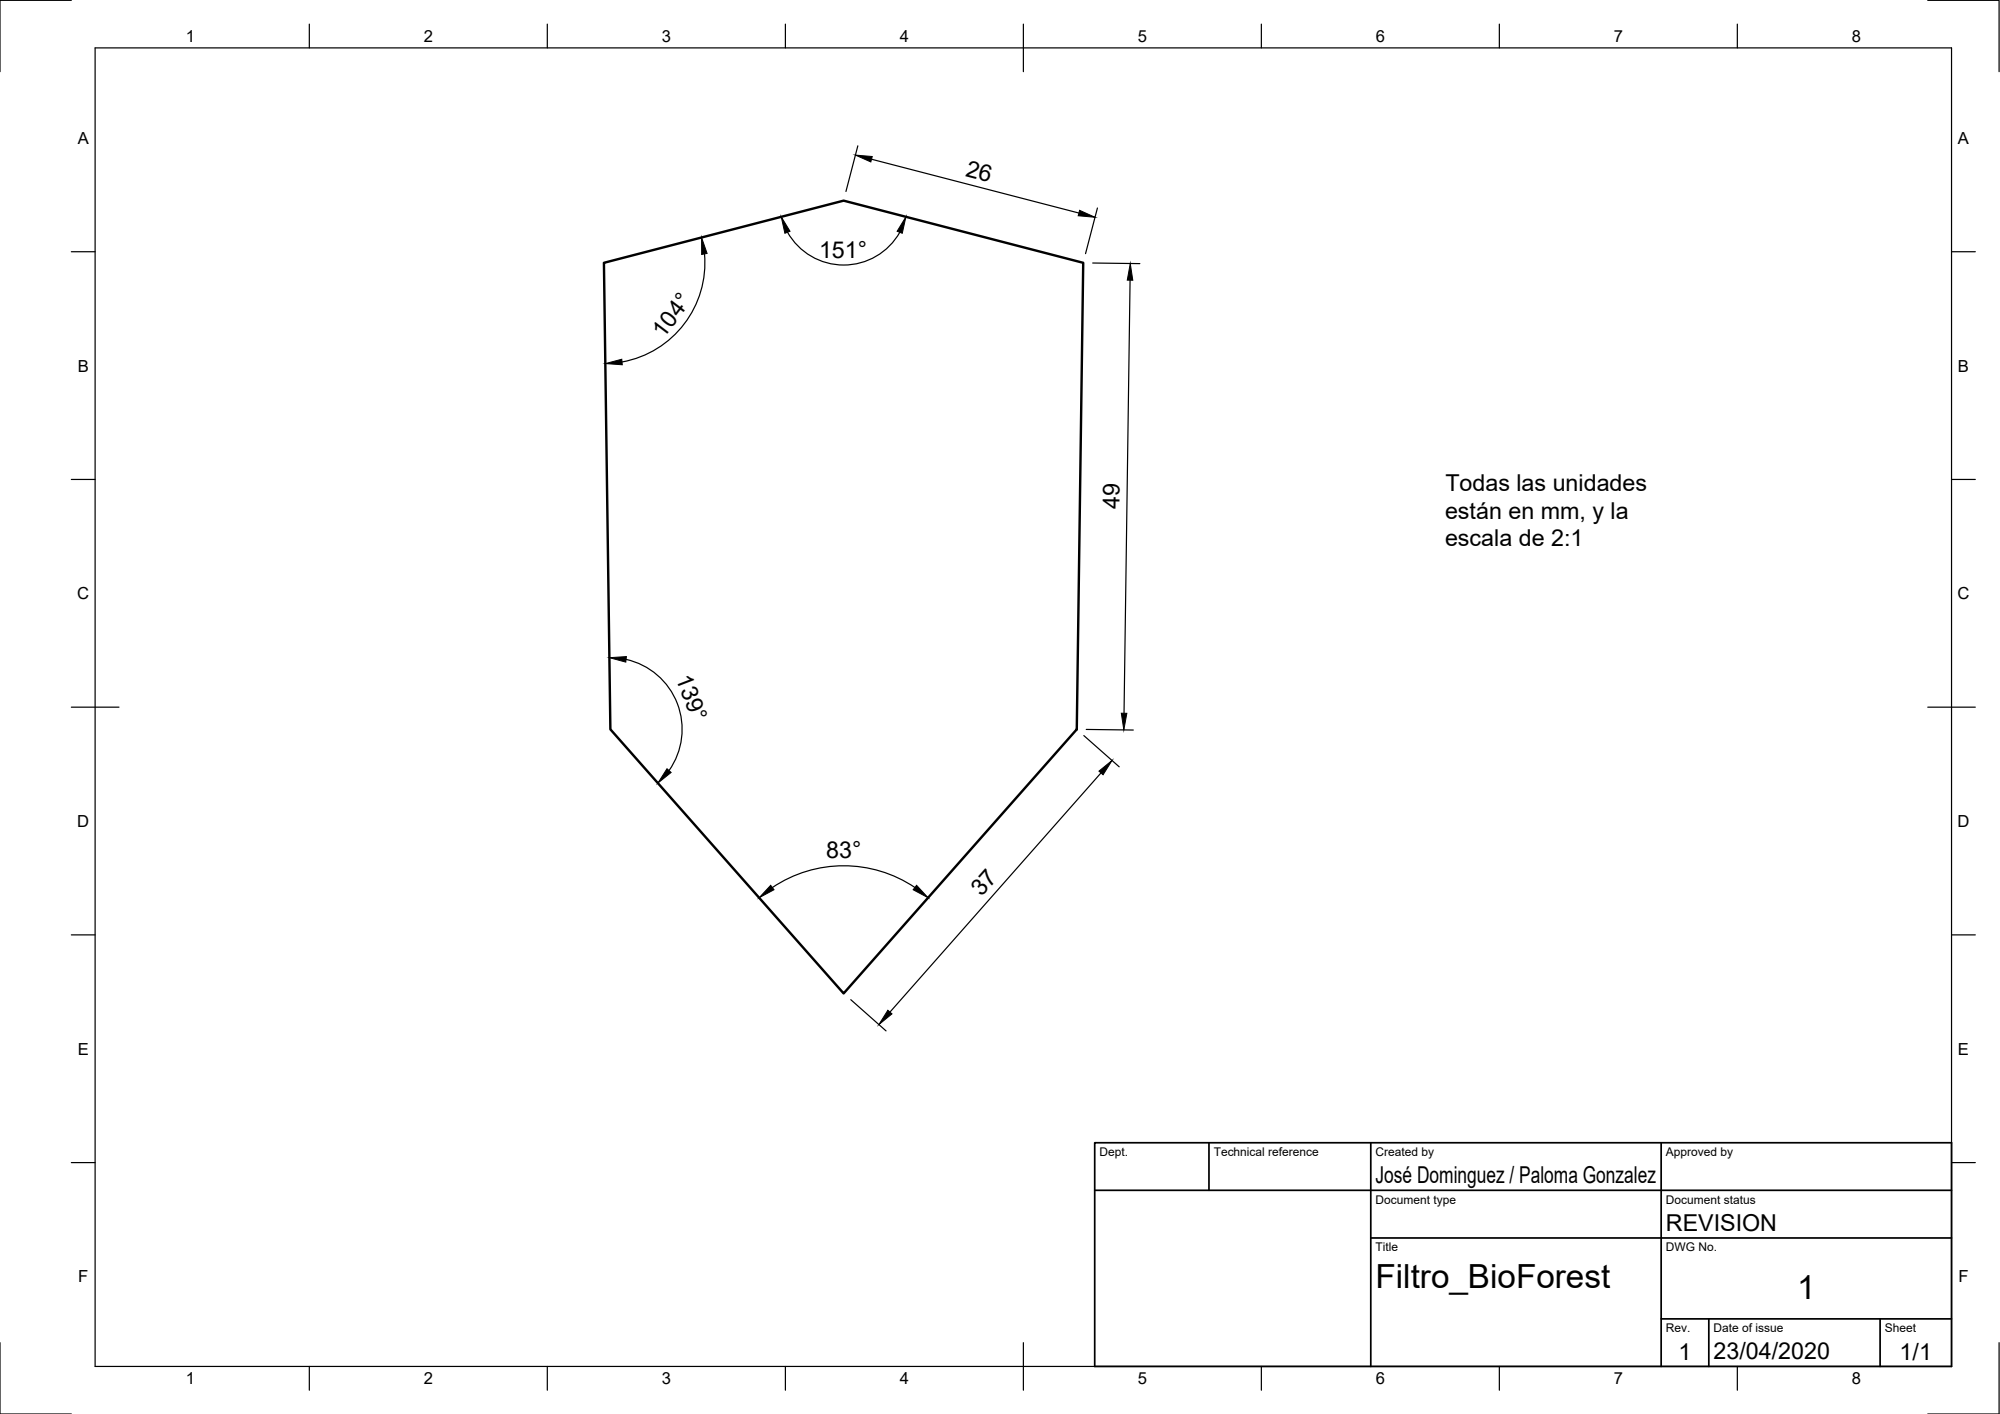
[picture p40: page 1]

Todas las unidades
están en mm, y la
escala de 2:1

José Dominguez / Paloma Gonzalez 49

Dept. | Technical reference | Created by | Approved by

Document type | Document status REVISION

Title | DWG No. 1 Filtro_BioForest

Rev. 1 | Date of issue 23/04/2020 | Sheet 1/1

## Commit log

2020-04-11 Model 1 documentation
    [M_1_1.stl]
2020-04-11 First mold documentation
2020-04-11 First mold documentation.
2020-04-12 cambiar nombre
    [M_1_1.stl]
2020-04-13 reordenar CAD
2020-04-20 Molde 1 netfabb
2020-04-21 NetFabb 2
    [Prueba_Prusa_Interior_4mm.stl]
